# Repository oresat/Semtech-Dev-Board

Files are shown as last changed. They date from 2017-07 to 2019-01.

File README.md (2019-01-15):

# Development board for the Semtech SX1236

## UPDATE: THIS PROJECT HAS BEEN DEPRECATED (RETIRED)

Because of the difficulty of getting the SX1236 to reliably work, we moved on to the On Semi AX5043. This project is now retired and won't be worked on any more.

-----

## Overview

OreSat is designed around a 70 cm (436 MHz) radio system for what other cubesats call their Command and Data Handling (C&DH) system. We started with the NXP Kw0x series chips but found that chip, and it's interface to its embedded Semtech SX1232 (?) radio IC, too painful to continue. 

Since the specs on the Semtech radio ICs are good, we could "upgrade" a generation by going to a separate IC, and we're interesting in using a STM32 for our system controller, we decided on using the SX1236. Of *course* no one makes an evaluation board for this IC. Sigh.

## Firmware

The current firmware to test this board is located in the [devsat repo under app_semtech](https://github.com/oresat/devsat/tree/master/firmware/chib_stf4x/src/app_semtech).

## Requirements

- Must be a barebones, "development" or "evaluation" board for the SX1236.
- Must work under USB and LiPo power
- Open source

## Specifications

- Must
   - RF out via Female SMA connector (board edge preferred)
   - Must have a 0.1" pinheader for power and control signals.
   - All but NC pads must be broken out to test points with vias for easy modding
   - Voltage input range of 3.0 to 5.5 V.
   - Use 0.1" headers and jumpers for configuration pins
- Should
   - Have large square silk screen area for board #
   - Have copper ground pads around edge of  board for scope clips
- Must not
   - Feature creep (don't go nuts, just make us an evaluation board of a refernece design)
   - This includes not bothering to deal with LNAs or PAs for this board! It's local only.

## References

- [Original Practicum Kw0x Development board](https://github.com/wrh2/sputnik/tree/master/Phase0/eagle)
- Original OreSat [Low Gain Radio board](https://github.com/oresat/low-gain-radio)
- [Semtech SX126 Webpage](http://www.semtech.com/wireless-rf/rf-transceivers/sx1236/)
- The [SX1276](http://www.semtech.com/apps/product.php?pn=SX1276) may have the same pinout, but also has a LoRa radio built in (blech)

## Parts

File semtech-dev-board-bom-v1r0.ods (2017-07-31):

Bill Of Materials for Semtech SX1236 Development Board
source file: semtech-dev-board.sch
Last modified: 2017/07/30
PCB version: 1.0 |  |  | P/DNP = | Place/Do Not Place (DNP is for final production boards)
BOM revision: 0 |  |  | Generic = | Any generic part with the same characteristics are OK (e.g., bypass cap)
Cnt | Part References | P/DNP | Mfg | Mfg PN | Description | Distributor | Dist. PN | Generic | Notes
1 | C1 | P | Yageo | CC0805KKX7R7BB106 | 10µF ±10% 16V Ceramic Capacitor X7R 0805 | Digi-Key | 311-3501-1-ND | Y
8 | C2, C11, C12, C13, C18, C19, C23, C24 | P | Yageo | CC0603KRX7R7BB104 | 0.1µF (100nF) ±10% 16V Ceramic Capacitor X7R 0603 | Digi-Key | 311-1088-1-ND | Y
1 | C3 | P | Yageo | CC0603KRX7R7BB105 | 1µF ±10% 16V Ceramic Capacitor X7R 0603 | Digi-Key | 311-1446-1-ND | Y
1 | C4 | P | Yageo | CC0603JRNPO9BN471 | 470pF ±5% 50V Ceramic Capacitor C0G, NP0 0603 | Digi-Key | 311-1520-1-ND | Y
1 | C5 | P | AVX | 06032U2R7BAT2A | 2.7pF ±0.1pF 200V Ceramic Capacitor C0G, NP0 0603 | Digi-Key | 478-3840-1-ND | N | High frequency
1 | C6 | P | AVX | 06031U220FAT2A | 22pF ±1% 100V Ceramic Capacitor C0G, NP0 0603 | Digi-Key | 478-10233-1-ND | N | High frequency
4 | C7, C10, C21, C22 | P | Yageo | CC0603JRNPO9BN150 | 15pF ±5% 50V Ceramic Capacitor C0G, NP0 0603 | Digi-Key | 311-1060-1-ND | Y
2 | C8, C14 | P | AVX | 06032U8R2BAT2A | 8.2pF ±0.1pF 200V Ceramic Capacitor C0G, NP0 0603 | Digi-Key | 478-10275-1-ND | N | High frequency
2 | C9, C15 | P | Yageo | CC0603KRX7R9BB103 | 10000pF (10nF) ±10% 50V Ceramic Capacitor X7R 0603 | Digi-Key | 311-1085-1-ND | N | High frequency
1 | C16 | P | AVX | 06032U6R8BAT2A | 6.8pF ±0.1pF 200V Ceramic Capacitor C0G, NP0 0603 | Digi-Key | 478-10274-1-ND | N | High frequency
1 | C17 | P | AVX | 06032U5R6BAT2A | 5.6pF ±0.1pF 200V Ceramic Capacitor C0G, NP0 0603 | Digi-Key | 478-10272-1-ND | N | High frequency
1 | C20 | P | AVX | 06032U4R7BAT2A | 4.7pF ±0.1pF 200V Ceramic Capacitor C0G, NP0 0603 | Digi-Key | 478-10270-1-ND | N | High frequency
4 | CF1, CF2, CF3, CF4 | P | Cinch Connectivity | 142-0701-806 | SMA Connector Jack, Female Socket 50 Ohm Board Edge | Digi-Key | J716-ND | Y
1 | CM1 | P | Hirose | ZX62D-B-5P8(30) | USB Micro B Receptacle Connector 5 Position SMT RA w/TH | Digi-Key | H125272CT-ND | Y
2 | JP1, JP2 | P | NA | NA | Generic 1x2 0.1" pin header | - | - | Y | From circuit store
2 | JP3, JP5 | P | NA | NA | Generic 1x4 0.1" pin header | - | - | Y | From circuit store
1 | JP4 | P | NA | NA | Generic 1x8 0.1" pin header | - | - | Y | From circuit store
1 | L1 | P | Murata | LQW18AN12NJ10D | 12nH Unshielded Wirewound Inductor 71 mOhm Max 0603 | Digi-Key | 490-6863-1-ND | N | High frequency
2 | L2, L4 | P | Murata | LQW18AN10NJ10D | 10nH Unshielded Wirewound Inductor 58 mOhm Max 0603 | Digi-Key | 490-6858-1-ND | N | High frequency
2 | L3, L5 | P | Murata | LQW18AN33NJ10D | 33nH Unshielded Wirewound Inductor 132 mOhm Max 0603 | Digi-Key | 490-6885-1-ND | N | High frequency
2 | L6, L7 | P | Murata | LQW18AN6N8D00D | 6.8nH Unshielded Wirewound Inductor 82 mOhm Max 0603 | Digi-Key | 490-1165-1-ND | N | High frequency
1 | L8 | P | Murata | LQW18AN3N9D00D | 3.9nH Unshielded Wirewound Inductor 59 mOhm Max 0603 | Digi-Key | 490-1160-1-ND | N | High frequency
1 | LED1 | P | Lite-On Inc. | LTST-C191KGKT | Green 571nm LED Indication - Discrete 2V 0603 | Digi-Key | 160-1446-1-ND | Y
1 | LED2 | P | Lite-On Inc. | LTST-C191AKT | Amber 602nm LED Indication - Discrete 2.1V 0603 | Digi-Key | 160-1440-1-ND | Y
1 | Q1 | P | Diodes Inc | DMN62D0U-13 | N-Channel 380mA (Ta) 380mW (Ta) Surface Mount SOT-23 | Digi-Key | DMN62D0U-13DICT-ND | Y
2 | R1, R3 | P | Yageo | RC0603FR-071KL | 1.00k ±1% 0.1W, 1/10W Chip Resistor 0603 | Digi-Key | 311-1.00KHRCT-ND | Y
2 | R2, R5 | P | Yageo | 311-10.0KHRCT-ND | 10.0k ±1% 0.1W, 1/10W Chip Resistor 0603 | Digi-Key | 311-10.0KHRCT-ND | Y
1 | R4 | P | Yageo | RC0603JR-070RL | 0 ohm Jumper 0.1W, 1/10W Chip Resistor 0603 | Digi-Key | 311-0.0GRCT-ND | Y
1 | S1 | P | TE Connectivity | FSM4JSMATR | Tactile Switch SPST-NO Top Actuated Surface Mount | Digi-Key | 450-1759-2-ND | Y
1 | U1 | P | Microchip | MIC5219-3.3YM5-TR | Linear Voltage Regulator IC Positive Fixed 3.3V 500mA SOT-23-5 | Digi-Key | 576-1281-1-ND | N
1 | U2 | P | Qualcomm/TDK/Epcos | B39431B3710U410 | FILTER SAW 433.92MHZ REMOTE SMD | Digi-Key | 495-1870-1-ND | N
1 | U3 | P | Qualcomm/TDK/Epcos | B39921B3588U410W9 | FILTER SAW 915MHZ REMOTE SMD | Digi-Key | 495-1674-1-ND | N
1 | U4 | P | Semtech | SX1236IMLTRT | IC RF TxRx Only General ISM < 1GHz 137MHz ~ 1.02GHz 28-VQFN Exposed Pad | Digi-Key | SX1236IMLTRTCT-ND | N
1 | Y1 | P | ECS | ECS-320-8-36CKM-TR | 32Mhz ±10ppm Crystal 8pF 50 Ohm -20°C ~ 70°C 4-SMD | Digi-Key | XC1563CT-ND | Y
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

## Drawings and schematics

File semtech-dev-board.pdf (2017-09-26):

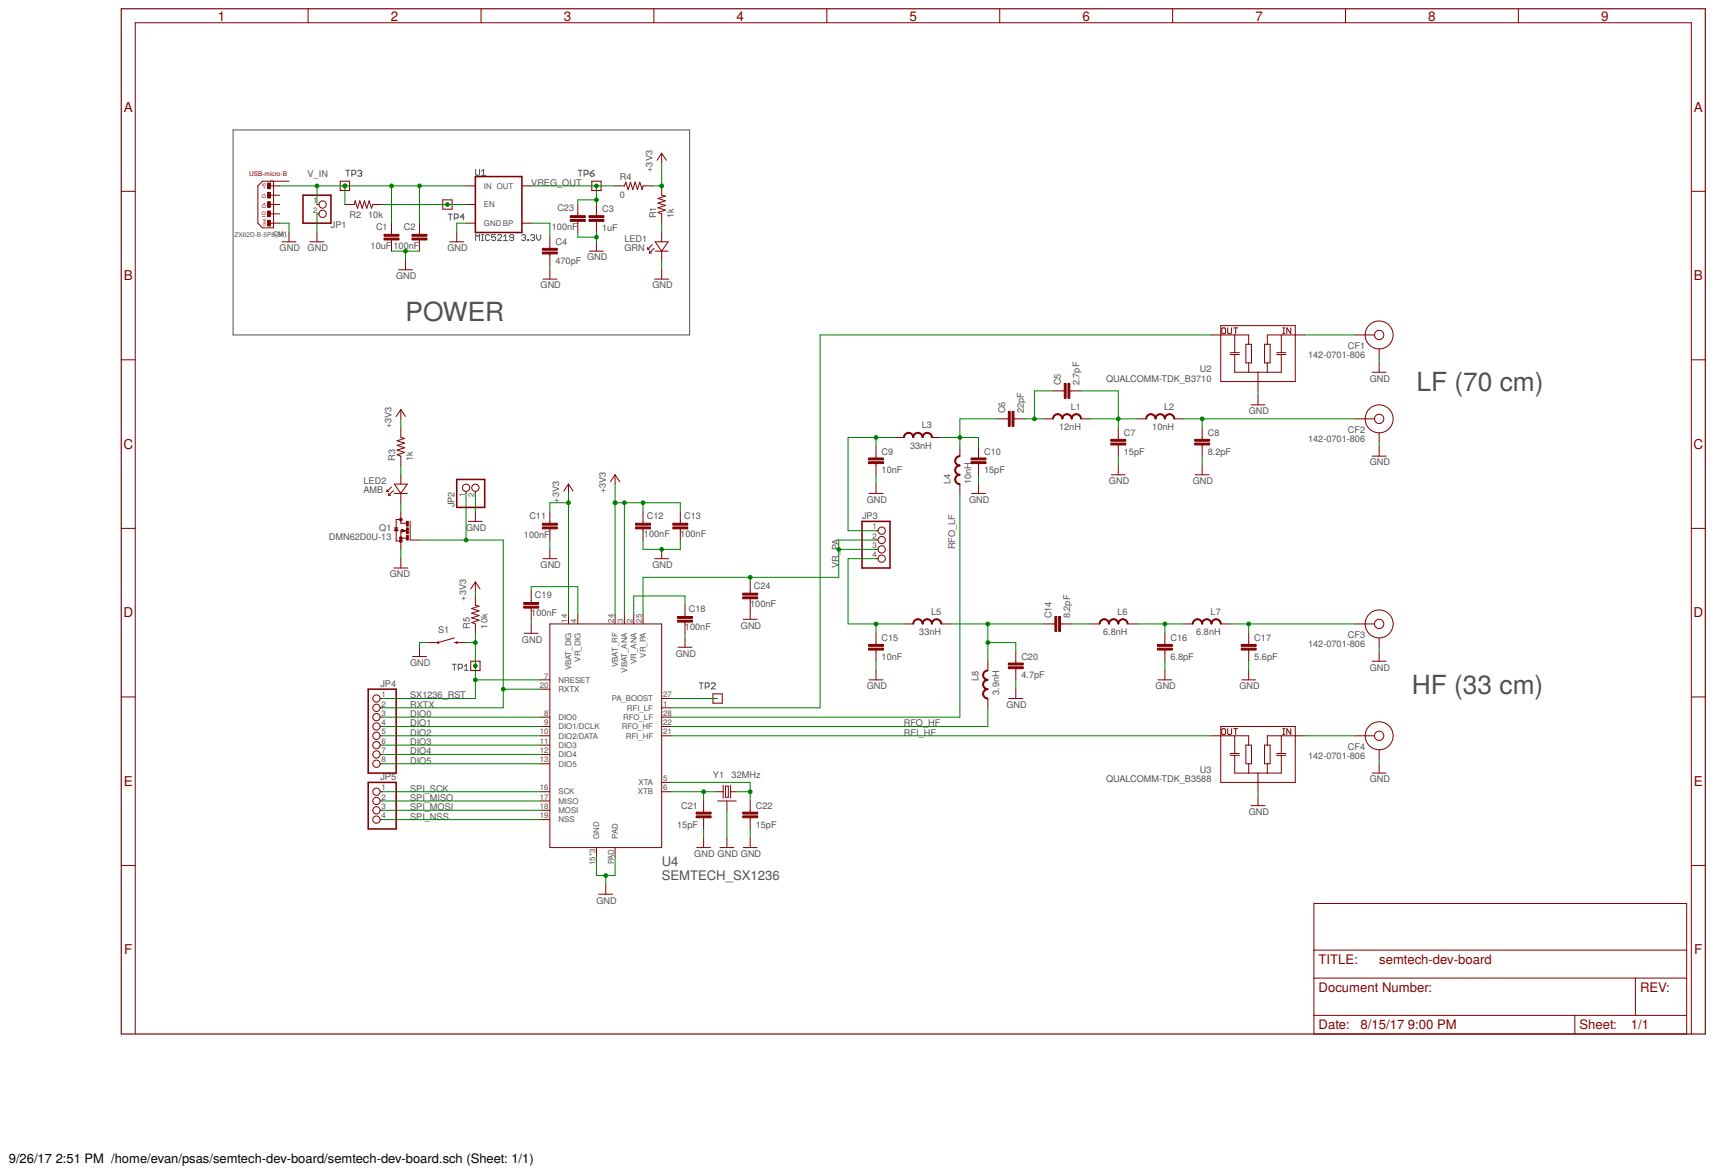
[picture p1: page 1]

Document Number: | REV:

Date: 8/15/17 9:00 PM | Sheet: 1/1

9/26/17 2:51 PM /home/evan/psas/semtech-dev-board/semtech-dev-board.sch (Sheet: 1/1)

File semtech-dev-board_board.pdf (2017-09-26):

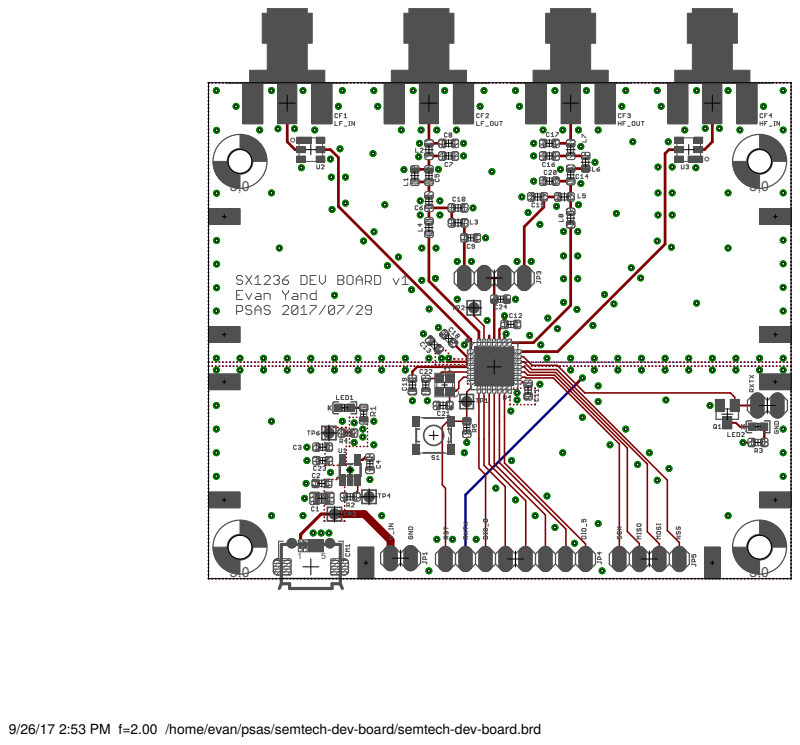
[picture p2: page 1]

9/26/17 2:53 PM f=2.00 /home/evan/psas/semtech-dev-board/semtech-dev-board.brd

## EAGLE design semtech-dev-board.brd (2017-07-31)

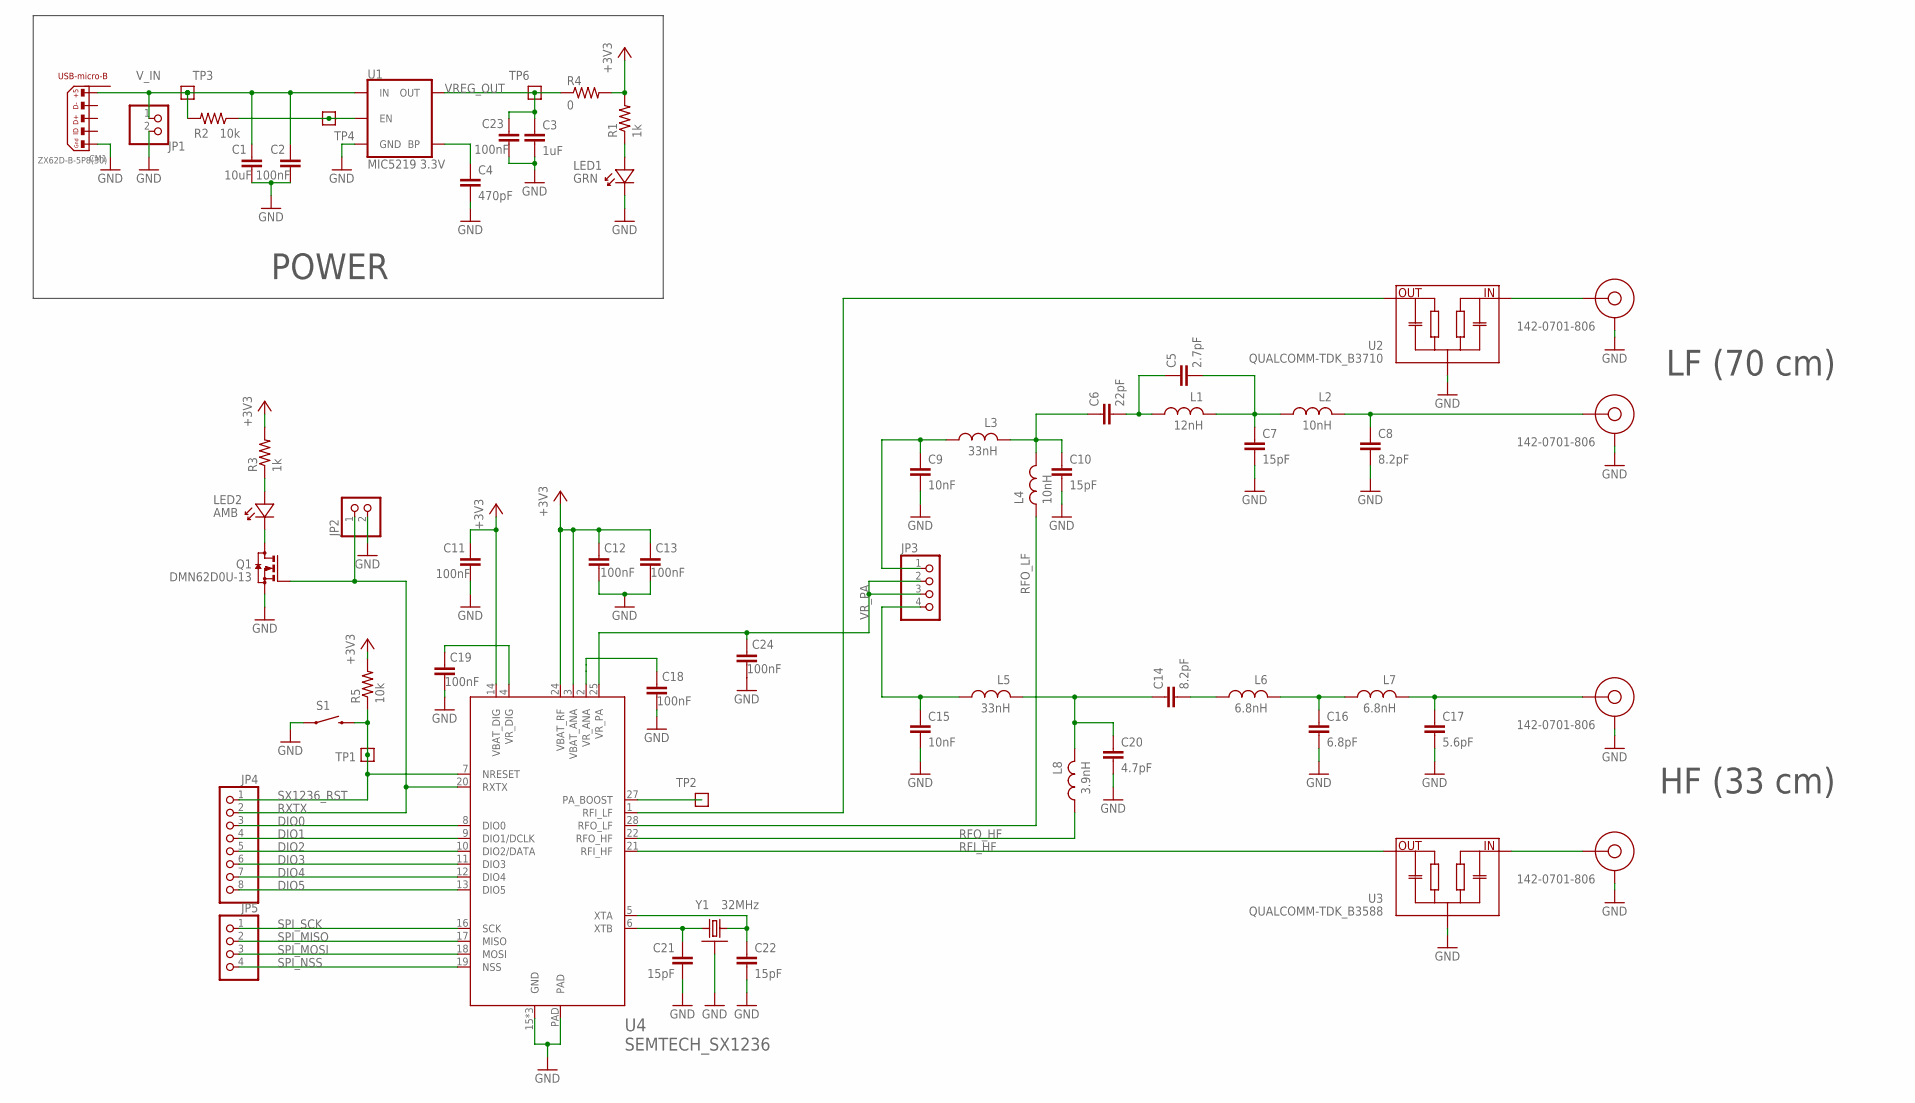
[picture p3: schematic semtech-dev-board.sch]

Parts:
C1: 10uF; .0805-B
C2, C11, C12, C13, C18, C19, C23, C24: 100nF; .0603-B-NOSILK
C3: 1uF; .0603-B-NOSILK
C4: 470pF; .0603-B-NOSILK
C5: 2.7pF; .0603-B-NOSILK
C6: 22pF; .0603-B-NOSILK
C7, C10, C21, C22: 15pF; .0603-B-NOSILK
C8, C14: 8.2pF; .0603-B-NOSILK
C9, C15: 10nF; .0603-B-NOSILK
C16: 6.8pF; .0603-B-NOSILK
C17: 5.6pF; .0603-B-NOSILK
C20: 4.7pF; .0603-B-NOSILK
CF1, CF2, CF3, CF4: 142-0701-806; SMAJ716-ND
CM1: ZX62D-B-5P8(30); USB-MICRO-B-PTH-HIROSE
JP1, JP2: PINHD-1X2; 1X02
JP3, JP5: PINHD-1X4; 1X04
JP4: PINHD-1X8; 1X08
L1: 12nH; .0603-B-NOSILK
L2, L4: 10nH; .0603-B-NOSILK
L3, L5: 33nH; .0603-B-NOSILK
L6, L7: 6.8nH; .0603-B-NOSILK
L8: 3.9nH; .0603-B-NOSILK
LED1: GRN; LED-0603
LED2: AMB; LED-0603
Q1: DMN62D0U-13; SOT23
R1, R3: 1k; .0603-B-NOSILK
R2, R5: 10k; .0603-B-NOSILK
R4: 0; .0603-B-NOSILK
S1: FSM4JSMATR; TACTILE_SWITCH_SMD-2
TP1, TP2, TP3, TP4, TP6: TEST-POINT; 2MM-TEST-POINT
U1: MIC5219 3.3V; SOT23-5
U2: QUALCOMM-TDK_B3710; DCC6C-EPCOS
U3: QUALCOMM-TDK_B3588; DCC6C-EPCOS
U4: SEMTECH_SX1236; QFN28
Y1: 32MHz; CRYSTAL_2.5X2

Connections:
+3V3: C11.1, C12.1, C13.1, R1.2, R3.2, R4.2, R5.2, U4.3 (VBAT_ANA), U4.14 (VBAT_DIG), U4.24 (VBAT_RF)
BP: C4.1, U1.4 (BP)
DIO0: JP4.3, U4.8 (DIO0)
DIO1: JP4.4, U4.9 (DIO1/DCLK)
DIO2: JP4.5, U4.10 (DIO2/DATA)
DIO3: JP4.6, U4.11 (DIO3)
DIO4: JP4.7, U4.12 (DIO4)
DIO5: JP4.8, U4.13 (DIO5)
GND: C1.2, C2.2, C3.2, C4.2, C7.2, C8.2, C9.2, C10.2, C11.2, C12.2, C13.2, C15.2, C16.2, C17.2, C18.2, C19.2, C20.2, C21.2, C22.2, C23.2, C24.2, CF1.GND1 (GND), CF1.GND2 (GND), CF1.GND3 (GND), CF1.GND4 (GND), CF2.GND1 (GND), CF2.GND2 (GND), CF2.GND3 (GND), CF2.GND4 (GND), CF3.GND1 (GND), CF3.GND2 (GND), CF3.GND3 (GND), CF3.GND4 (GND), CF4.GND1 (GND), CF4.GND2 (GND), CF4.GND3 (GND), CF4.GND4 (GND), CM1.5, JP1.2, JP2.2, LED1.K, Q1.2 (S), S1.2 (1), U1.2 (GND), U2.1 (GND), U2.3 (GND), U2.4 (GND), U2.6 (GND), U3.1 (GND), U3.3 (GND), U3.4 (GND), U3.6 (GND), U4.15 (GND), U4.23 (GND), U4.26 (GND), U4.PAD, Y1.2 (SHIELD), Y1.4 (SHIELD)
HFO_PA_HEAD: C15.1, JP3.4, L5.2
LED+: LED2.A, R3.1
LED-: LED2.K, Q1.3 (D)
LFO_PA_HEAD: C9.1, JP3.1, L3.2
unnamed: R2.1, TP4.1, U1.3 (EN)
unnamed: CF4.P$3 (CENTERCONDUCTOR), U3.2 (IN)
unnamed: CF1.P$3 (CENTERCONDUCTOR), U2.2 (IN)
unnamed: LED1.A, R1.1
PA_BOOST: TP2.1, U4.27 (PA_BOOST)
RFI_HF: U3.5 (OUT), U4.21 (RFI_HF)
RFI_LF: U2.5 (OUT), U4.1 (RFI_LF)
RFO_HF: L8.2, U4.22 (RFO_HF)
RFO_HF_1: C14.2, L6.2
RFO_HF_2: C16.1, L6.1, L7.2
RFO_HF_OUT: C17.1, CF3.P$3 (CENTERCONDUCTOR), L7.1
RFO_HF_PA: C14.1, C20.1, L5.1, L8.1
RFO_LF: L4.1, U4.28 (RFO_LF)
RFO_LF_1: C5.1, C6.2, L1.2
RFO_LF_2: C5.2, C7.1, L1.1, L2.2
RFO_LF_OUT: C8.1, CF2.P$3 (CENTERCONDUCTOR), L2.1
RFO_LF_PA: C6.1, C10.1, L3.1, L4.2
RXTX: JP2.1, JP4.2, Q1.1 (G), U4.20 (RXTX)
SPI_MISO: JP5.2, U4.17 (MISO)
SPI_MOSI: JP5.3, U4.18 (MOSI)
SPI_NSS: JP5.4, U4.19 (NSS)
SPI_SCK: JP5.1, U4.16 (SCK)
SX1236_RST: JP4.1, R5.1, S1.1 (2), TP1.1, U4.7 (NRESET)
VREG_OUT: C3.1, C23.1, R4.1, TP6.1, U1.5 (OUT)
VR_ANA: C18.1, U4.2 (VR_ANA)
VR_DIG: C19.1, U4.4 (VR_DIG)
VR_PA: C24.1, JP3.2, JP3.3, U4.25 (VR_PA)
V_IN: C1.1, C2.1, CM1.1, JP1.1, R2.2, TP3.1, U1.1 (IN)
XTALA: C22.1, U4.5 (XTA), Y1.3 (2)
XTALB: C21.1, U4.6 (XTB), Y1.1

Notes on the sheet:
POWER
LF (70 cm)
HF (33 cm)

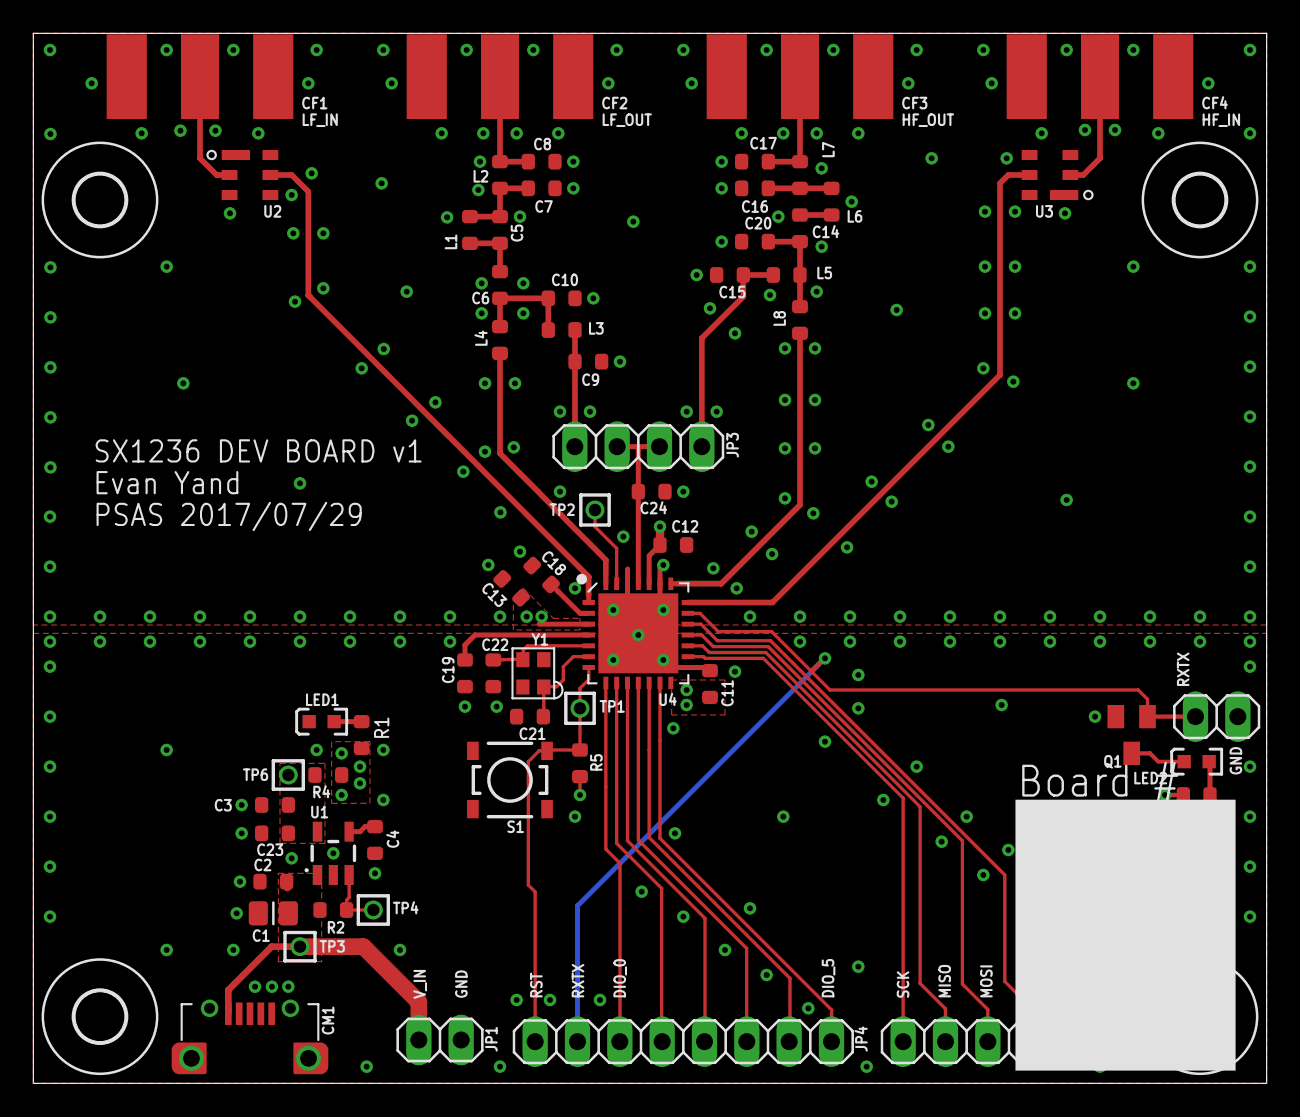
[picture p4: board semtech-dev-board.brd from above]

Board: 4 copper layers, 74.0 x 63.0 mm, 75 parts (0 on the bottom side), 43 nets.

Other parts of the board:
U$1, U$2, U$3, U$5, U$6, U$7, U$12, U$13, U$14, U$15: SCOPE_CLIP
U$8, U$9, U$10, U$11: 3,0

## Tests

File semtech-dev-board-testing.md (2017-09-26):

# This is incomplete and is still in process! - GNL

## Testing strategy for the Semtech Dev Board

The following tests should be performed to verify the functionality of the development board.

### General tests to get started

* Equipment needed:
  * Power supply
  * 3M wires (and possibly USB-micro cable for power)
  * DVM for current measurement
  * Laptop
  * Embedded system and software (M4) to talk SPI
  * Three (3) 2W SMA terminators
  * SMA "rubber duck" antenna

* Power up, and see that no smoke is emitted
  * Place 2W terminators on SMA connectors CF2, 3, and 4. Place a *rubber duck* antenna on connector CF1.
  * Make power connection (5 VDC through USB, or JP1) and SPI connections. Also a connection to DIO2 is needed for data.
  * Connect jumper for PA Bias. Only connect the LF side for now, JP3 1-2.
  * Apply power and verify LED indicates power is on. **Verify no smoke is emitted!**
  * Measure current consumption of the board in this idle state and record it [where?] as a baseline value.

* CPU communication to the SX1236 using SPI
  * Ability to read a register and confirm data is valid.
  * Ability to write a register and read back the correct value.
  * Confirm registers (how many?) have their POR values in them as expected.
  * Read back the temperature sensor register (0x3c) and verify it makes sense.

### Setup for emperical RF test and measurement

* Equipment needed:
  * RF signal generator
  * Throughline RF power meter
  * Spectrum Analyser and sampling antenna (RTL-SDR on another laptop)
  * SMA patch cords
  * 3M wires to generate Data I/O
  * 10k ohm leaded 1/4 watt resistor.
  * Oscilloscope to view data I/O

The SX1236 has three bands it can operate in:
- Band 3:  137 to 175 MHz
- Band 2:  410 to 525 MHz
- Band 1:  862 to 1020 MHz

The SX1236 has two digital (IQ) transceivers available:
- HF (Band 1)
- LF (Band 2 and 3)

#### Setup for transmitter tests

Let's go right to where we plan to use this thing (i.e. communications in the 435 to 438 MHz Amateur Space Band.)

Using the LF transceiver, and knowing our crystal oscillator (FXOSC) is 32 MHz;

Presently K has created SX1233 firmware test code on an M4 to communicate over SPI to generate beacon signals using packet
mode. This firmware could be used for this test without the need to apply data I/O to DIO2. 

* Set LO synthesizer frequency (FR) to 436.5 MHz
* Set FSK bit rate (BRF) to 9.6 kbps (BitRate MSB/LSB are set to 4.8 kbps upon POR)
* Set FSK deviation (FDA) to 20 kHz (Fdev is set to 5 kHz upon POR)
* Set data processing mode to Continuous Mode. This is because (sadly) we will need to do our own packet processing to adhear
  to other standards such as AX.25. Here we will use DIO2 for data input / output.
* Set output power to 0 dBm
* Set up spectrum analyser to sample 430 to 440 MHz band
* Insert throughline power meter between CF2 and 2W terminator.
* If using continuous mode, assert DIO2 to a logic high level using a 10k ohm pullup to Vcc and a 3M wire.

This sets us up for signals compatible with the G3RUH modulation standard, and we are ready to "key-up" the transmitter.

##### Turn on transmitter

* Confirm frequency on SA
* Confirm power level on throughline power meter

##### Send data through transmitter

* Confirm data sent by observing on SA
  * Alternately a second Semtech board could be used to receive the data sent over the air, but that system and test has not
    yet been described but will be in subsequent tests.

#### Setup for receiver tests

Using the same embedded system in the transmitter test, perform the following:

* Set LO synthesizer frequency (FR) to 436.5 MHz
* Set FSK bit rate (BRF) to 9.6 kbps
* Set FSK deviation (FDA) to 20 kHz
* Set LNA gain to [lowest gain]
* Remove the rubber duck antenna from CF1, and connect RF signal generator using SMA patch cables.
  * Set RF signal generator to -60 dBm level and frequency of 436.5 MHz continuous wave (no modulation)

##### Measure known receive signal

* Read RSSI register and confirm it is seeing the -60 dBm (LNA gain should be 0 dB)

##### Receive known data packet

* At this point a second system could be used to send a known data packet, and the received data couls be confirmed.
* Remove the RF signal generator from CF1, and reconnect the rubber duck antenna.
* Using K's firmware on the M4 monitor the received packet data through the SPI. DIO0 should assert an interrupt pulse
  when a packet is received.

###

Register usage for tests:

* Packet mode

* Continuous mode

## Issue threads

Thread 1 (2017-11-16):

review C4 and C3 value relationship

kwilsonpdx, 2017-11-16:
From https://psas.zulipchat.com/# discussion 16 November 2017

```
In trying to identify the source of the terrible ripple seen on the Semtech dev board 3v3
supply rail, I discovered in the MIC5219 LDO data sheet, when using a 470 pF cap on C4,
the output cap C3 needs to be 2.2 uF or greater. Without C4, C3 can be 1.0 uF. Well we
incorrectly designed the board using C4, but with C3 set to 1.0 uF.

To confirm this error, I tested two Semtech dev boards (SN-3, and SN-8) with a 4.7 uF in
place of C3, and the nearly 800 mV ripple completely went away for all practical purposes.
If C3 were set to only 2.0 uF, the ripple remained, but was reduced to under 100 mV.

I would like to ask that at some point soon, each of these boards be brought into the lab to
have their C3 replaced with 4.7 uF, or even go as far as replacing with 10 uF. This could
possibly reduce erratic behaviour observed with some of the boards.

```

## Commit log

2017-07-03 Aha, found the old practicum board.
2017-07-03 Started schematic
    [semtech-dev-board.sch]
2017-07-03 started on power
    [semtech-dev-board.sch]
2017-07-03 added vreg
    [semtech-dev-board.sch]
2017-07-03 created brd file
    [semtech-dev-board.brd, semtech-dev-board.sch]
2017-07-05 Connected power supply
    [semtech-dev-board.sch]
2017-07-05 named nets
    [semtech-dev-board.sch]
2017-07-05 Fixed bus
    [semtech-dev-board.sch]
2017-07-09 adjustments based on Friday meeting
    [semtech-dev-board.brd, semtech-dev-board.sch]
2017-07-09 Updates from Sunday meeting
    [semtech-dev-board.brd, semtech-dev-board.sch]
2017-07-10 added biasing circuitry to match ref design for sx1233
    [semtech-dev-board.brd, semtech-dev-board.sch]
2017-07-12 formatted sch
    [semtech-dev-board.brd, semtech-dev-board.sch]
2017-07-12 started 4 layer board
    [semtech-dev-board.brd, semtech-dev-board.sch]
2017-07-13 Fixed inductors
    [semtech-dev-board.brd, semtech-dev-board.sch]
2017-07-14 Draft arrangement of components
    [semtech-dev-board.brd, semtech-dev-board.sch]
2017-07-14 board draft
    [semtech-dev-board.brd]
2017-07-14 minor edits
    [semtech-dev-board.brd, semtech-dev-board.sch]
2017-07-19 started routing, adjusted placement, named nets
    [semtech-dev-board.brd, semtech-dev-board.sch]
2017-07-21 Removed caps
    [semtech-dev-board.brd, semtech-dev-board.sch]
2017-07-24 Components placed, 80% routed
    [semtech-dev-board.brd, semtech-dev-board.sch]
2017-07-25 97% routed, needs vias, mounts, scope clips, and vals
    [semtech-dev-board.brd, semtech-dev-board.sch]
2017-07-25 Filter values updated
    [semtech-dev-board.brd, semtech-dev-board.sch]
2017-07-26 Tuesday D/R
    [semtech-dev-board.brd, semtech-dev-board.sch]
2017-07-26 reworked board based on feedback, needs mounting holes
    [semtech-dev-board.brd, semtech-dev-board.sch]
2017-07-27 added holes
    [semtech-dev-board.brd]
2017-07-30 Board clean up from Evan's excellent first draft. Fixed SMA connectors, SAW filters, and 1236 packages. Made sure passives were from rlc_custom. More stiching, isolate on polygons, added a mounting h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
    [semtech-dev-board.brd, semtech-dev-board.sch]
2017-07-30 TNAMES cleanup, better ground plane splitting - probably TOTALLY unnecessary on this board, but whatevs, it's fun. Updated SX1236 symbol, switched digital/analog caps to be correct.
    [semtech-dev-board.brd, semtech-dev-board.sch]
2017-07-30 Added cap to VR_PA, because it said to. Probably overkill, given the other ones.
    [semtech-dev-board.brd, semtech-dev-board.sch]
2017-07-31 Added updated BOM, and adjusted inductor sizes
    [semtech-dev-board.brd, semtech-dev-board.sch, semtech-dev-board_v1_BOM.ods]
2017-07-31 reformatted BOM
    [semtech-dev-board_v1_BOM.ods]
2017-07-31 added place column to bom
    [semtech-dev-board_v1_BOM.ods]
2017-07-31 New format for BOM; still needs parts chosen.
    [semtech-dev-board-bom-v1r0.ods, semtech-dev-board_v1_BOM.ods]
2017-07-31 Chose parts and added Digikey part numbers to BoM, switched inductors to 0603 because it was easy, shrunk board by 3 mm, cleaned up stapling, switched LEDs to 0603, oh and added a power LED for fun.
    [semtech-dev-board-bom-v1r0.ods, semtech-dev-board.brd, semtech-dev-board.sch]
2017-07-31 Tent vias. They're all ground anyway, so might as well make it easy to solder and not blow up.
    [semtech-dev-board.brd]
2017-07-31 Whoah - almost missed the fixed to the crystal from the LGR board. Kenny would have totally killed us all.
    [semtech-dev-board.brd, semtech-dev-board.sch]
2017-09-06 Added semtech-dev-board-registers.h which contains intended register contents for initial testing
2017-09-10 Added spreadsheet describing register details and updated semtech-dev-board-registers.h to reflect changes.
    [SX1236_Registers.ods]
2017-09-26 added pdfs of eagle schematics

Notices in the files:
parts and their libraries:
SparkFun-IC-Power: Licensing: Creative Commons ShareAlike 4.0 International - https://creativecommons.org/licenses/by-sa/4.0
